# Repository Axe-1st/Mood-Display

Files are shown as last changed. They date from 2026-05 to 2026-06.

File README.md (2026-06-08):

# Mood-Display
## A Round Pin badge display! Powered by an Integrated ESP32-S3-WROOM-1 and a 1.28 in round display MoodBadge clips easily to your ID lanyard, keychain, belt, Bag, and so many more. You can easily express your mood or any animations you want to play on the display!

> Hiya! This project is still in its designing stage! When i build it, I will make a step by step video how to assemble 

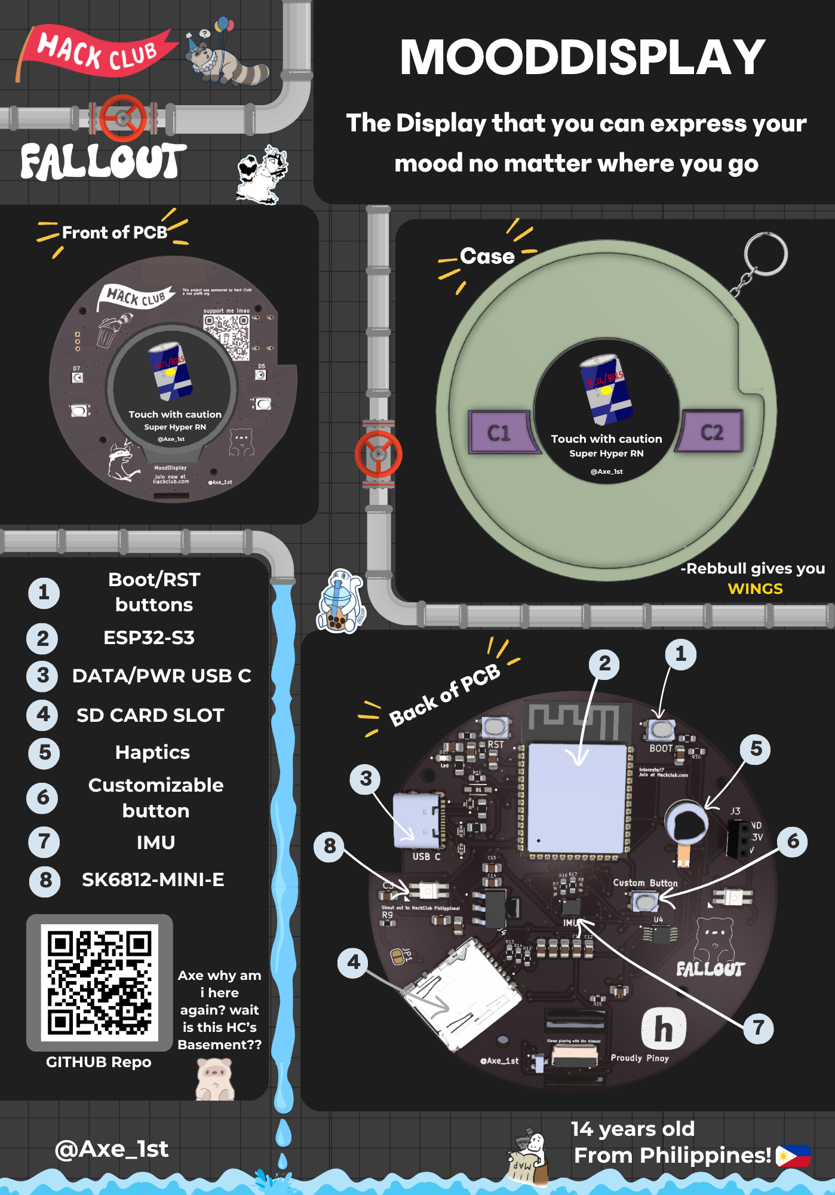
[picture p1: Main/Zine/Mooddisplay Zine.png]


> PDF is available in Zine folder!

### I made this project because i was inspired by those mini circular displays that you can bring anywhere! 
### This exsist since i wanted a badge that i can interact with.
### This project is pretty easy to do, All you need to do is follow the tutorial (Scoll down)

### Some kind of important notes!
- This is powered by USB C <b>ONLY</b>
- yes that means you have to always have a powerbank around with u to power it!
- reason for this: It would increase project cost and its complexity. 

## Schematic


> for a much better image check the pdf in extras!

## PCB


## PCB Render
- back


- Front


## Cad
- Onshape link:https://cad.onshape.com/documents/fe18899c0fc823d496ae247b/w/1ef647bd25a6a14e89f050fb/e/3a17c80e85047fb88fb13b3e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

> I love Onshape Man





## How to Build it 
- 1st step: Get the Requied materials in BOM.CSV and get the Gerber file in the folder production.
- 2nd Step: Pay JLC PCB to Fabricate the PCB and Use the links in the BOM.CSV to order parts
> You should def order a stencil! But for this tutorial i will be doing it manualy

- 3rd Step: Get your solder paste then manualy little solder to each pad that needs a connection. Also have a tissue nearby!
> Remember Patience is better than Crashing Out!

- 4th step: Start placing the compoments then when you are ready, use a hot plate to reflow all of the connections!
> For this part you would be Placing compoments at the back of the pcb so that means the front side of the pcb is facing flat on the hotplate
> When reflowing feel free to gently adjust the possiton of the compoments!

- 5th step: Now you have the backside of the pcb done! After letting the PCB rest now flip it to the other side, you should see some pads there. You are going to use a normal soldering iron to solder the buttons and other DIP compoments like the power Headers!

- 6th Step: Congradulations! You are done with the PCB!! Now kindly please test it by powering it on with a type C cable (please make sure it gets enough power to boot). Flash the test firmware i have provided it should light up the leds!

- if you like the bare PCB you can now stop here and use any of the mounting holes to attach the Mood-Display with anything!

- After this it would be Optional to do the case!

- 7th Step: Print all of the Case Parts then start assembling it by starting with the bottom. With the Bottom place the pcb on top and it line up with the mounting holes! When it is fully alligned screw the holes! Now get your assembles Bottom Case and carefully insert it up to the "middle case part" then super glue it! Now place and glue the Top Cover!
> i have used the terms "bottom case" "Middle Part" "Top Cover" why? because i have provided three parts in the CAD. 

- Final Step: There is no final step Lmao. Enjoy your own Mood display!

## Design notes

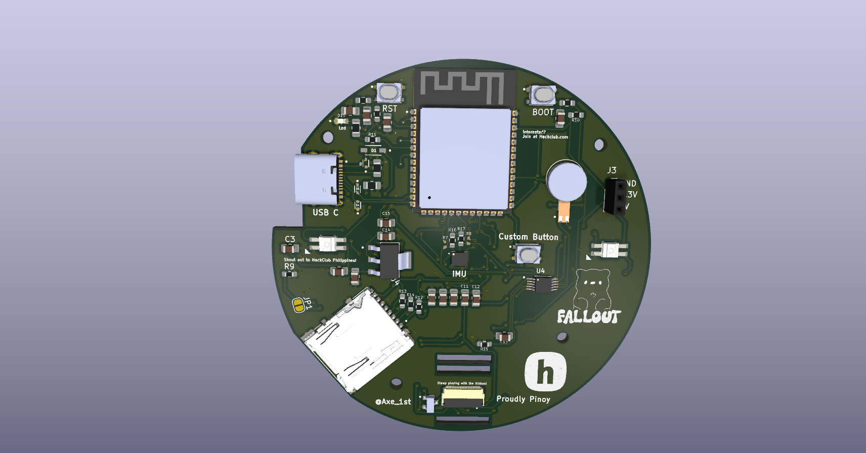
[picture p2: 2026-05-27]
Main/Extras/Display back.png

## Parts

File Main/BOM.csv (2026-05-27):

Product | Link | Quantity | Price USD | total
ESP32-S3-WROOM-1 | https://jlcpcb.com/partdetail/3198295-ESP32_S3_WROOM_1N4/C2913197 | 1 | $4.49 | $4.49
FFC2B28-12-G | https://www.digikey.ph/en/products/detail/gct/FFC2B28-12-G/10656933?s=N4IgTCBcDaIGJwMJgEJgBwFoCMZMHEACEAXQF8g | 1 | $0.40 | $0.40
LESD5D5.0CT1G | https://jlcpcb.com/partdetail/LRC-LESD5D50CT1G/C383211 | 3 | $0.40 | $1.20
1N5819HW-7-F | https://jlcpcb.com/partdetail/DiodesIncorporated-1N5819HW_7F/C82544 | 1 | $0.04 | $0.04
2.4k resistor | https://www.digikey.ph/en/products/detail/panasonic-industry/ERA-2AEB242X/1706014 | 2 | $0.11 | $0.22
4.7k resistor | https://www.digikey.ph/en/products/detail/yageo/RC0402JR-074K7L/726477 | 7 | $0.10 | $0.70
SK-Mini-e | https://jlcpcb.com/partdetail/OPSCOOptoelectronics-SK6812MINIE/C5149201 | 2 | $0.09 | $0.18
C2912598 | https://jlcpcb.com/partdetail/C2912598 | 2 | $0.08 | $0.16
Resistor | https://jlcpcb.com/partdetail/RESI-PTFR0805B200RP9/C2849095 | 5 | $0.07 | $0.35
Type C female | https://jlcpcb.com/parts/componentSearch?searchTxt=C2765186 | 1 | $0.09 | $0.09
JLCPCB | JLCPCB | 1 | $2.00 | $2.00
10uf cap | https://www.digikey.ph/en/products/detail/samsung-electro-mechanics/CL21A106KAYNNNG/3894413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 | 5 | $0.09 | $0.45
1uf capacitor | https://www.digikey.ph/en/products/detail/samsung-electro-mechanics/CL10A105KO8NNNC/3886692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 | 2 | $0.10 | $0.20
10 ohm resistor | https://www.digikey.ph/en/products/detail/stackpole-electronics-inc/RNCP0603FTD10K0/2240139 | 5 | $0.01 | $0.06
CAP CER 0.1UF 50V X7R 0603 | https://www.digikey.ph/en/products/detail/samsung-electro-mechanics/CL10B104KB8NNNL/3894274 | 10 | $0.03 | $0.27
4518-AMS1117-3.3TR-ND | https://www.digikey.ph/en/products/detail/umw/AMS1117-3-3/17635254 | 1 | $0.30 | $0.30
399-C0603C220J5GAC7867TR-ND | https://www.digikey.ph/en/products/detail/kemet/C0603C220J5GACTU/411055 | 2 | $0.13 | $0.26
smd Buttons | https://www.digikey.ph/en/products/detail/c-k/PTS810SJG250SMTR-LFS/4176612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 | 5 | $0.65 | $3.25
Pwr led | https://www.digikey.ph/en/products/detail/liteon/LTST-C190TBKT/388529?s=N4IgTCBcDaIIwDYAMBaRAWBKwoHIBEQBdAXyA | 1 | $0.17 | $0.17
2N7002 | https://www.digikey.ph/en/products/detail/diotec-semiconductor/2N7002/13163336 | 1 | $0.16 | $0.16
DLC-T1.3CDS#1 | https://www.digikey.ph/en/products/detail/dlc-display-co-ltd/DLC-T1-3CDS-1/26822644 | 1 | $17.97 | $17.97
C0720B001F | https://www.digikey.ph/en/products/detail/vybronics-inc/VC0720B001F/6009905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 | 1 | $3.23 | $3.23
DRV2605LDGST | https://www.digikey.ph/en/products/detail/texas-instruments/DRV2605LDGST/5023854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 | 1 | $3.45 | $3.45
BMI270 | https://www.digikey.ph/en/products/detail/bosch-sensortec/BMI270/9974486 | 1 | $4.23 | $4.23
DM3AT-SF-PEJM5 | https://www.digikey.com/en/products/detail/hirose-electric-co-ltd/DM3AT-SF-PEJM5/2533565 | 1 | $2.85 | $2.85
 |  |  |  | TOTAL
 |  |  |  | $36.15

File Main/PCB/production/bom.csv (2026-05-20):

Designator | Footprint | Quantity | Value | LCSC Part #
C1, C14, C2, C4, C7 | 0805 | 5 | 10uF
C10, C15, C3, C5, C6, C9 | 0805 | 6 | 0u1F
C11, C12 | 0805 | 2 | 100nF
C13, C8 | 0805 | 2 | 1uF
D1 | SOD3715X145N | 1 | 1N5819HW-7-F
D15 | LEDC1608X35N | 1 | LTST-C190KGKT
D2, D3, D4 | TVS_LESD5D5.0CT1G | 3 | LESD5D5.0CT1G
D5, D7 | SK6812MINI-E_fixed | 2 | SK6812MINI-E
J1 | HRO_TYPE-C-31-M-12 | 1 | TYPE-C-31-M-12
J2 | GCT_FFC2B28-12-G | 1 | FFC2B28-12-G
J3 | PinSocket_1x03_P2.00mm_Vertical | 1 | Conn_01x03
J4 | HRS_DM3AT-SF-PEJM5 | 1 | DM3AT-SF-PEJM5
M1 | XDCR_C0720B001F | 1 | C0720B001F
Q1 | TRANS_2N7002 | 1 | 2N7002
R1, R2 | 0805 | 2 | 5k1
R10, R11, R12, R13, R14, R16, R17 | 0603 | 7 | 4.7k
R15, R4, R5, R6, R9 | 0603 | 5 | 10k
R3 | 0805 | 1 | 75
R7, R8 | RES_ERA2AEB242X | 2 | 2.4k
SW1, SW2, SW3, SW4, SW5 | SW_PTS810_SJM_250_SMTR_LFS | 5 | PTS810_SJM_250_SMTR_LFS
U1 | SOT229P700X180-4N | 1 | AMS1117-3.3
U2 | XCVR_ESP32-S3-WROOM-1-N16R2 | 1 | ESP32-S3-WROOM-1-N16R2
U3 | XDCR_BMI270 | 1 | BMI270
U4 | SOP50P490X110-10N | 1 | DRV2605LDGST

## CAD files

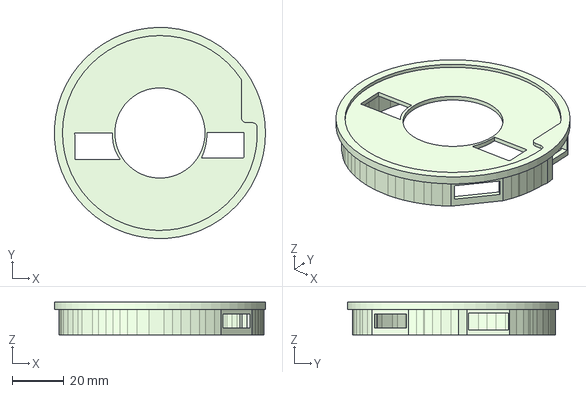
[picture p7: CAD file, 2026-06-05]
Main/CAD/Part Studio 1 - Top Case cover.step
81.6 x 81.6 x 12.7 mm

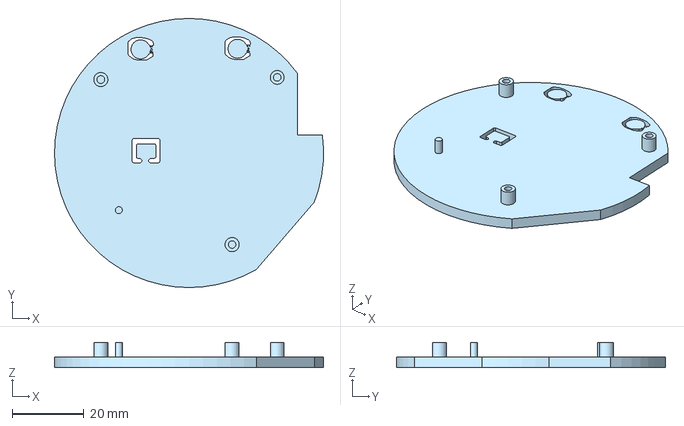
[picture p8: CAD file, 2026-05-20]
Production/CAD/Part Studio 1 - Bottom Case.step
75.0 x 75.1 x 7.00 mm

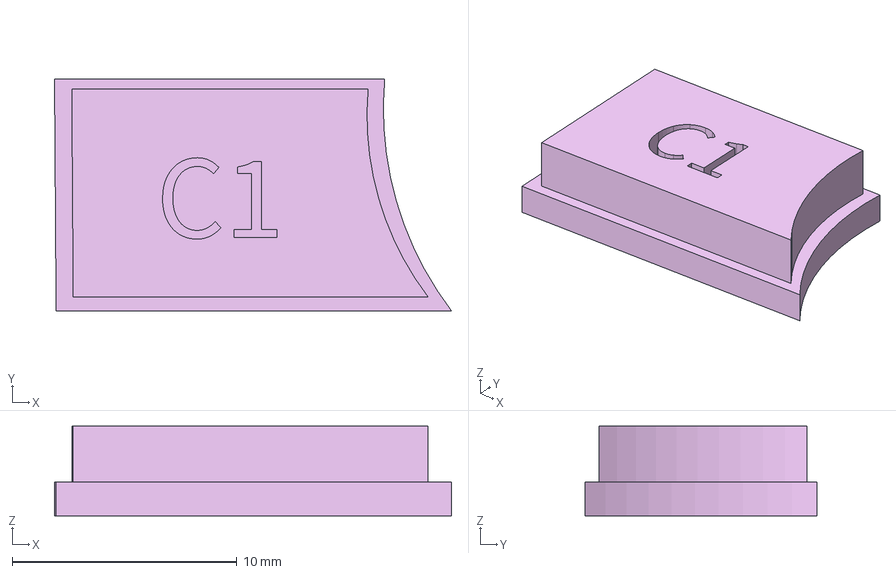
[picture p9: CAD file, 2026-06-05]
Main/CAD/Part Studio 1 - Left Button.step
17.7 x 10.3 x 4.00 mm

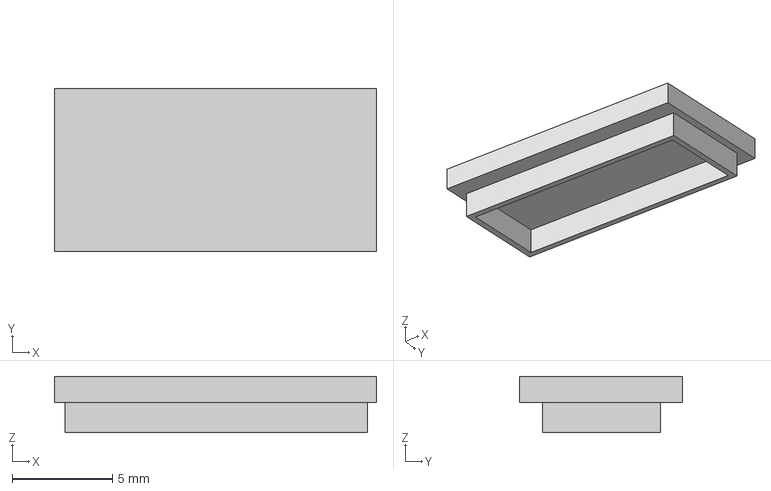
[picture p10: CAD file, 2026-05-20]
Production/CAD/Part Studio 1 - USB C COVER.step
16.1 x 8.13 x 2.80 mm

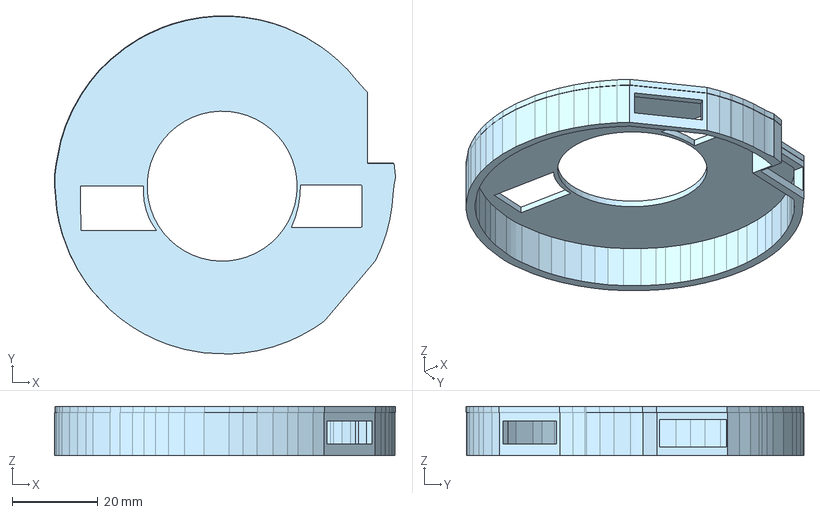
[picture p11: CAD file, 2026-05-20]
Production/CAD/Part Studio 1 - Top Case cover.step
79.4 x 78.6 x 11.5 mm

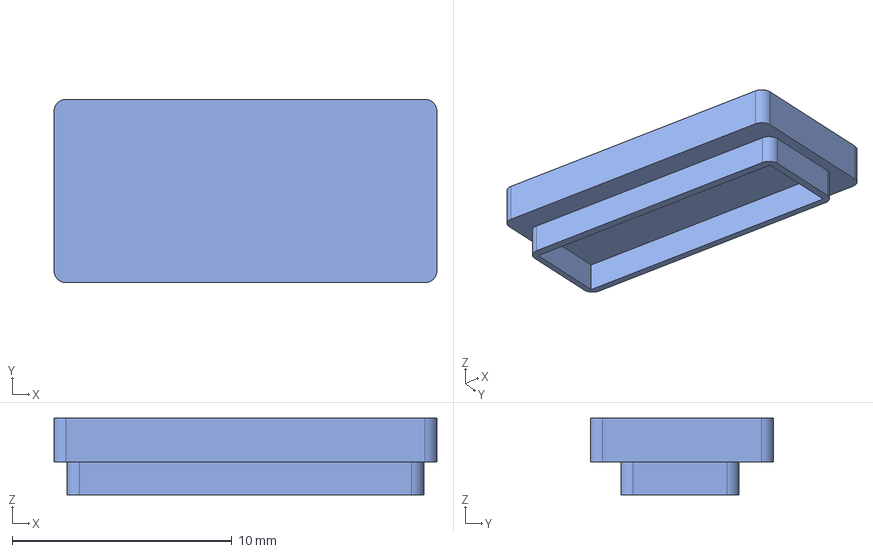
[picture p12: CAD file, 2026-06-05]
Main/CAD/Part Studio 1 - SD Card slot Cover.step
17.4 x 8.35 x 3.50 mm

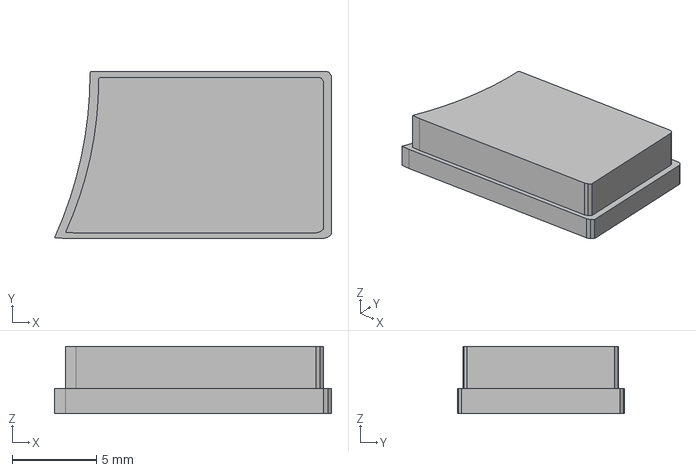
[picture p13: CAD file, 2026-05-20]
Production/CAD/Part Studio 1 - Right Button.step
16.4 x 9.92 x 4.00 mm

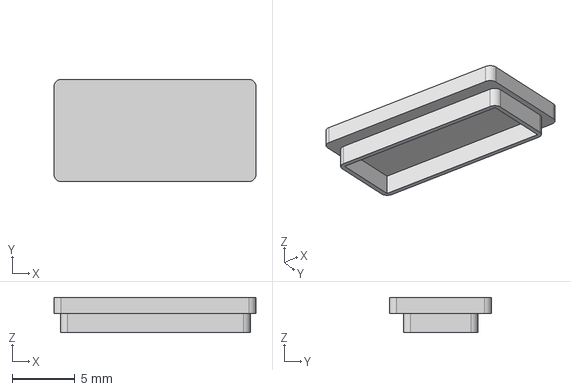
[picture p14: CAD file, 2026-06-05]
Main/CAD/Part Studio 1 - USB C COVER.step
16.1 x 8.13 x 2.80 mm

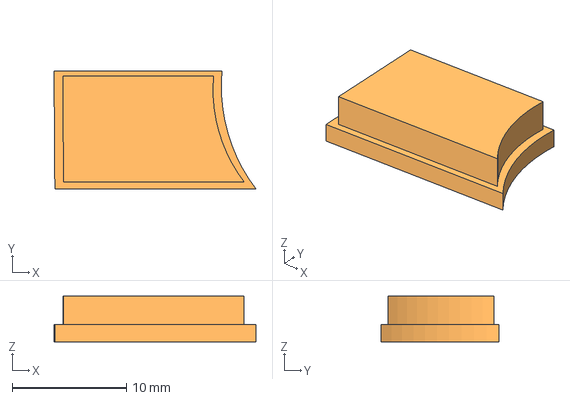
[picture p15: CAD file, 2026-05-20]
Production/CAD/Part Studio 1 - Left Button.step
17.7 x 10.3 x 4.00 mm

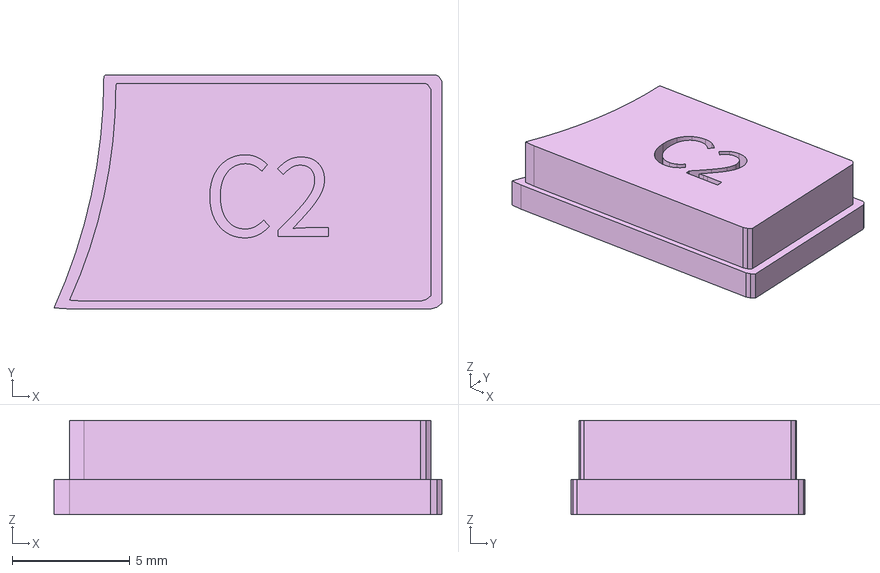
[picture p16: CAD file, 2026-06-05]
Main/CAD/Part Studio 1 - Right Button.step
16.4 x 9.92 x 4.00 mm

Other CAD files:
Main/CAD/Part Studio 1 - Bottom Case.step
Production/CAD/Part Studio 1 - SD Card slot Cover.step

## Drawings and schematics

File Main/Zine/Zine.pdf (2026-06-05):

# MOODDISPLAY

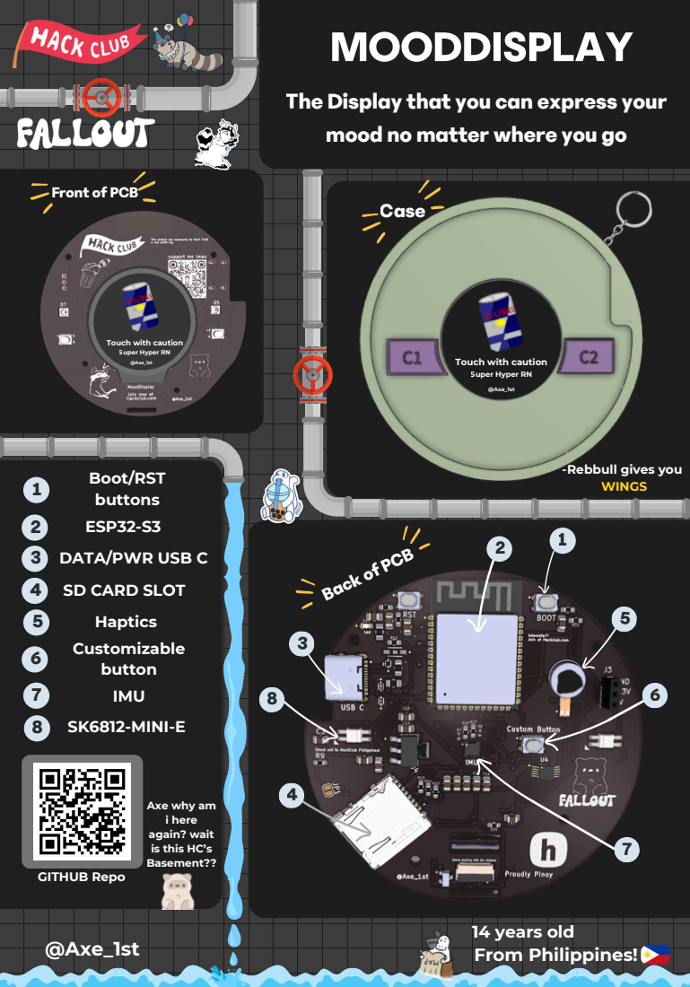
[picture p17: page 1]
From Philippines!; Case; @Axe_1st; Boot/RST buttons; ESP32-S3; DATA/PWR USB C; SD CARD SLOT; Haptics; Customizable button; IMU; SK6812-MINI-E; 14 years old; GITHUB Repo

The Display that you can express your
mood no matter where you go

Front of PCB

Touch with caution
Super Hyper RN @Axe_1st

-Rebbull gives you
WINGS

Back of PCB

Axe why am
i here
again? wait
is this HC’s
Basement??

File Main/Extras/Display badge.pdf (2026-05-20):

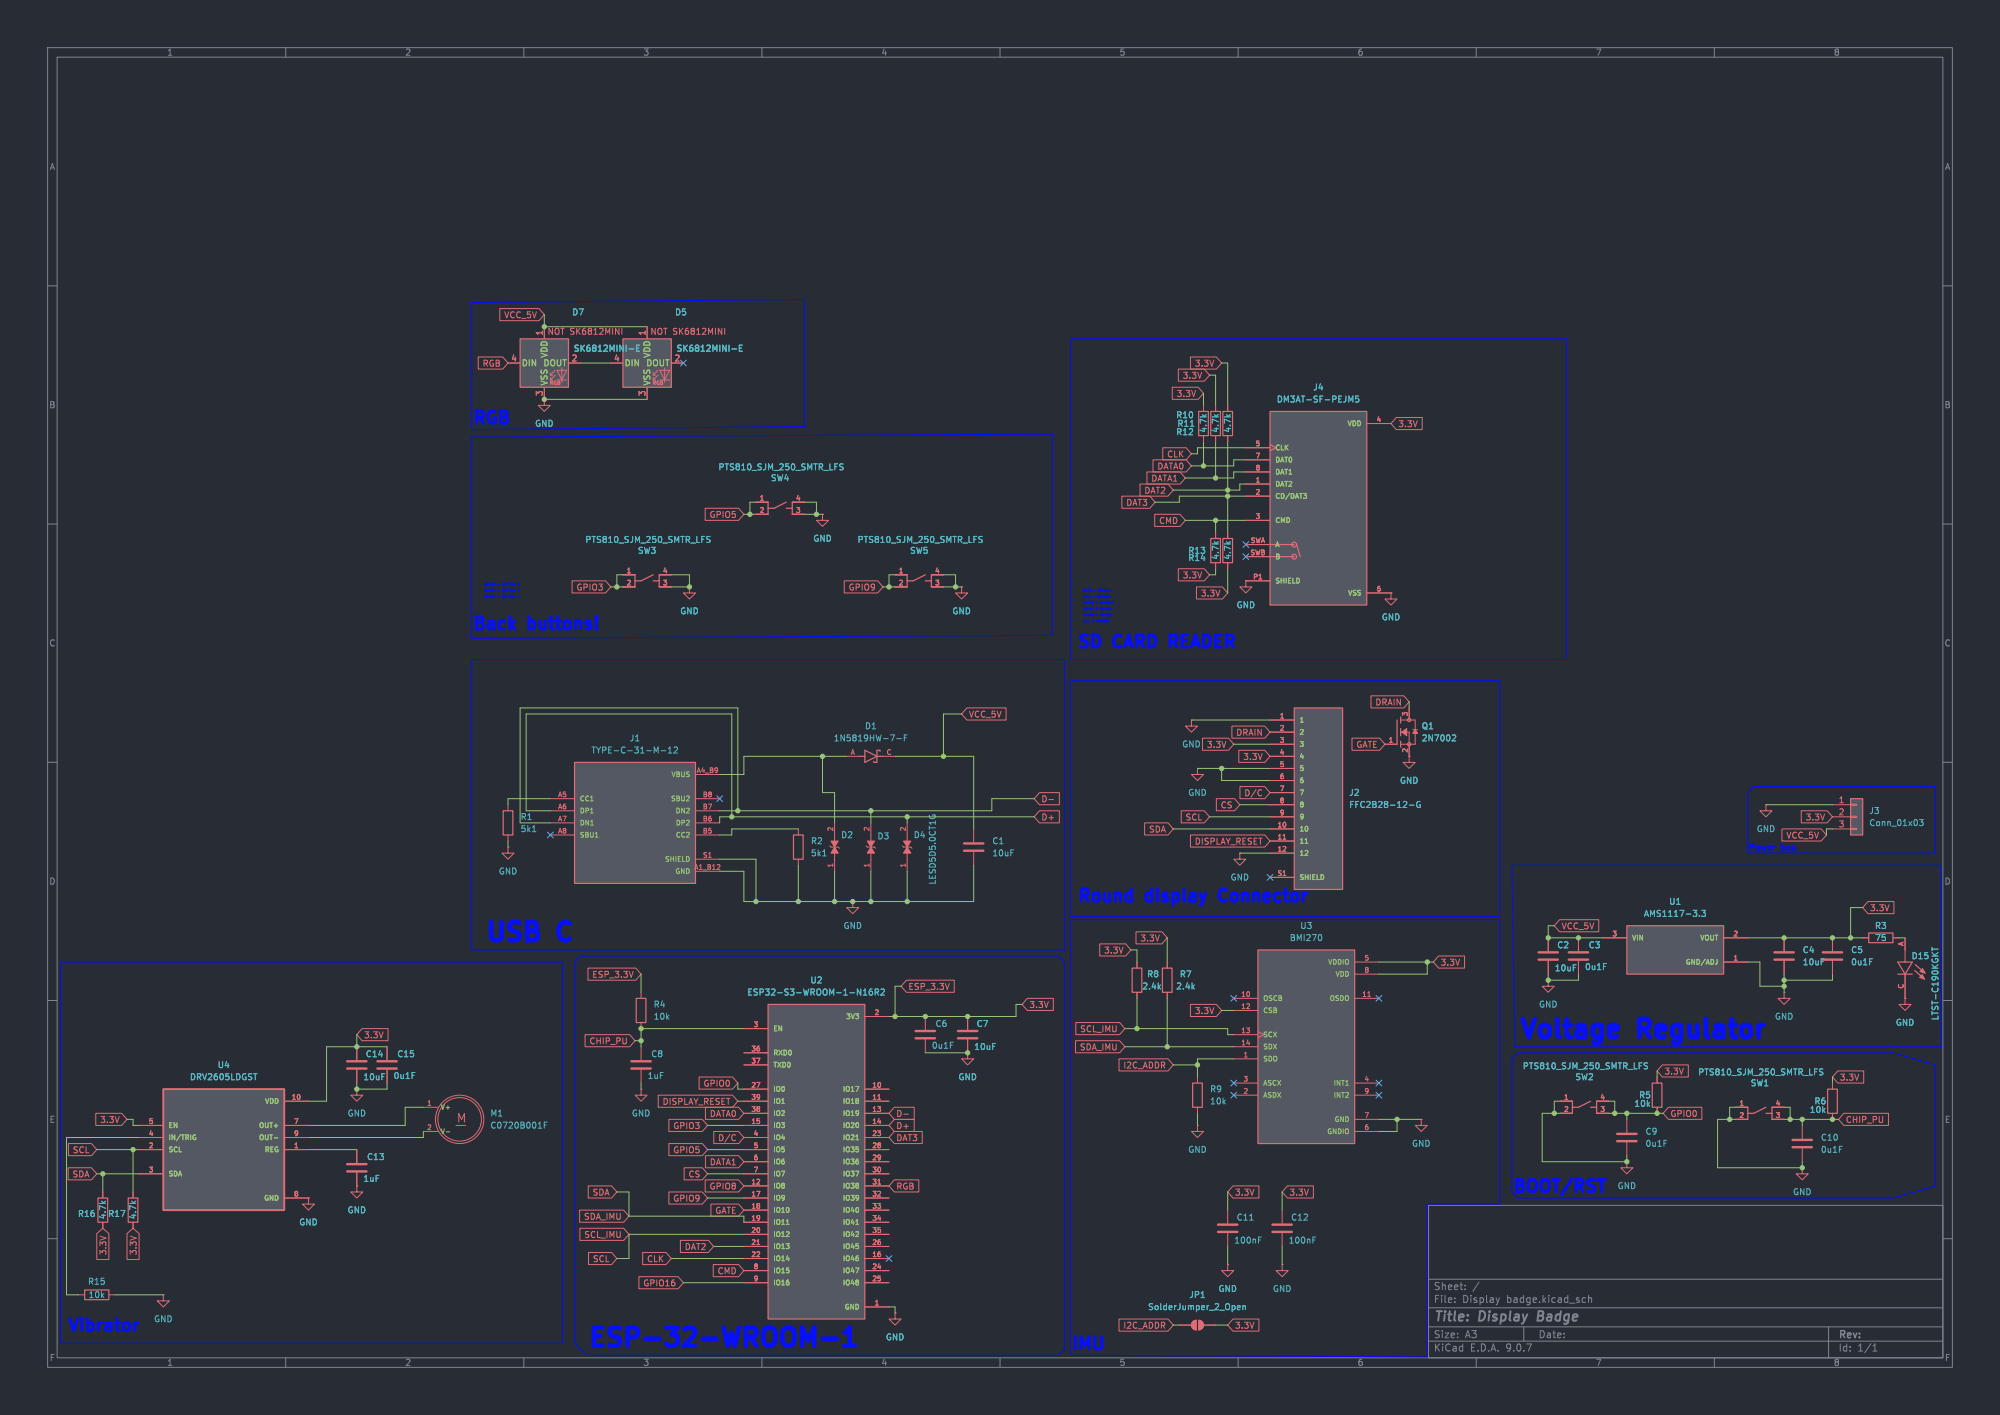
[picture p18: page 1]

GPIO9 = BUTTON 3 GPIO3 = BUTTON 1 GPIO5 = BUTTON 2 Back buttons!

DATA1 = GPIO6 CLK = GPIO14 DATA2 = GPIO13 Round display Connector
DATA0 = GPIO2 SD CARD READER

Id: 1/1 Title: Display Badge

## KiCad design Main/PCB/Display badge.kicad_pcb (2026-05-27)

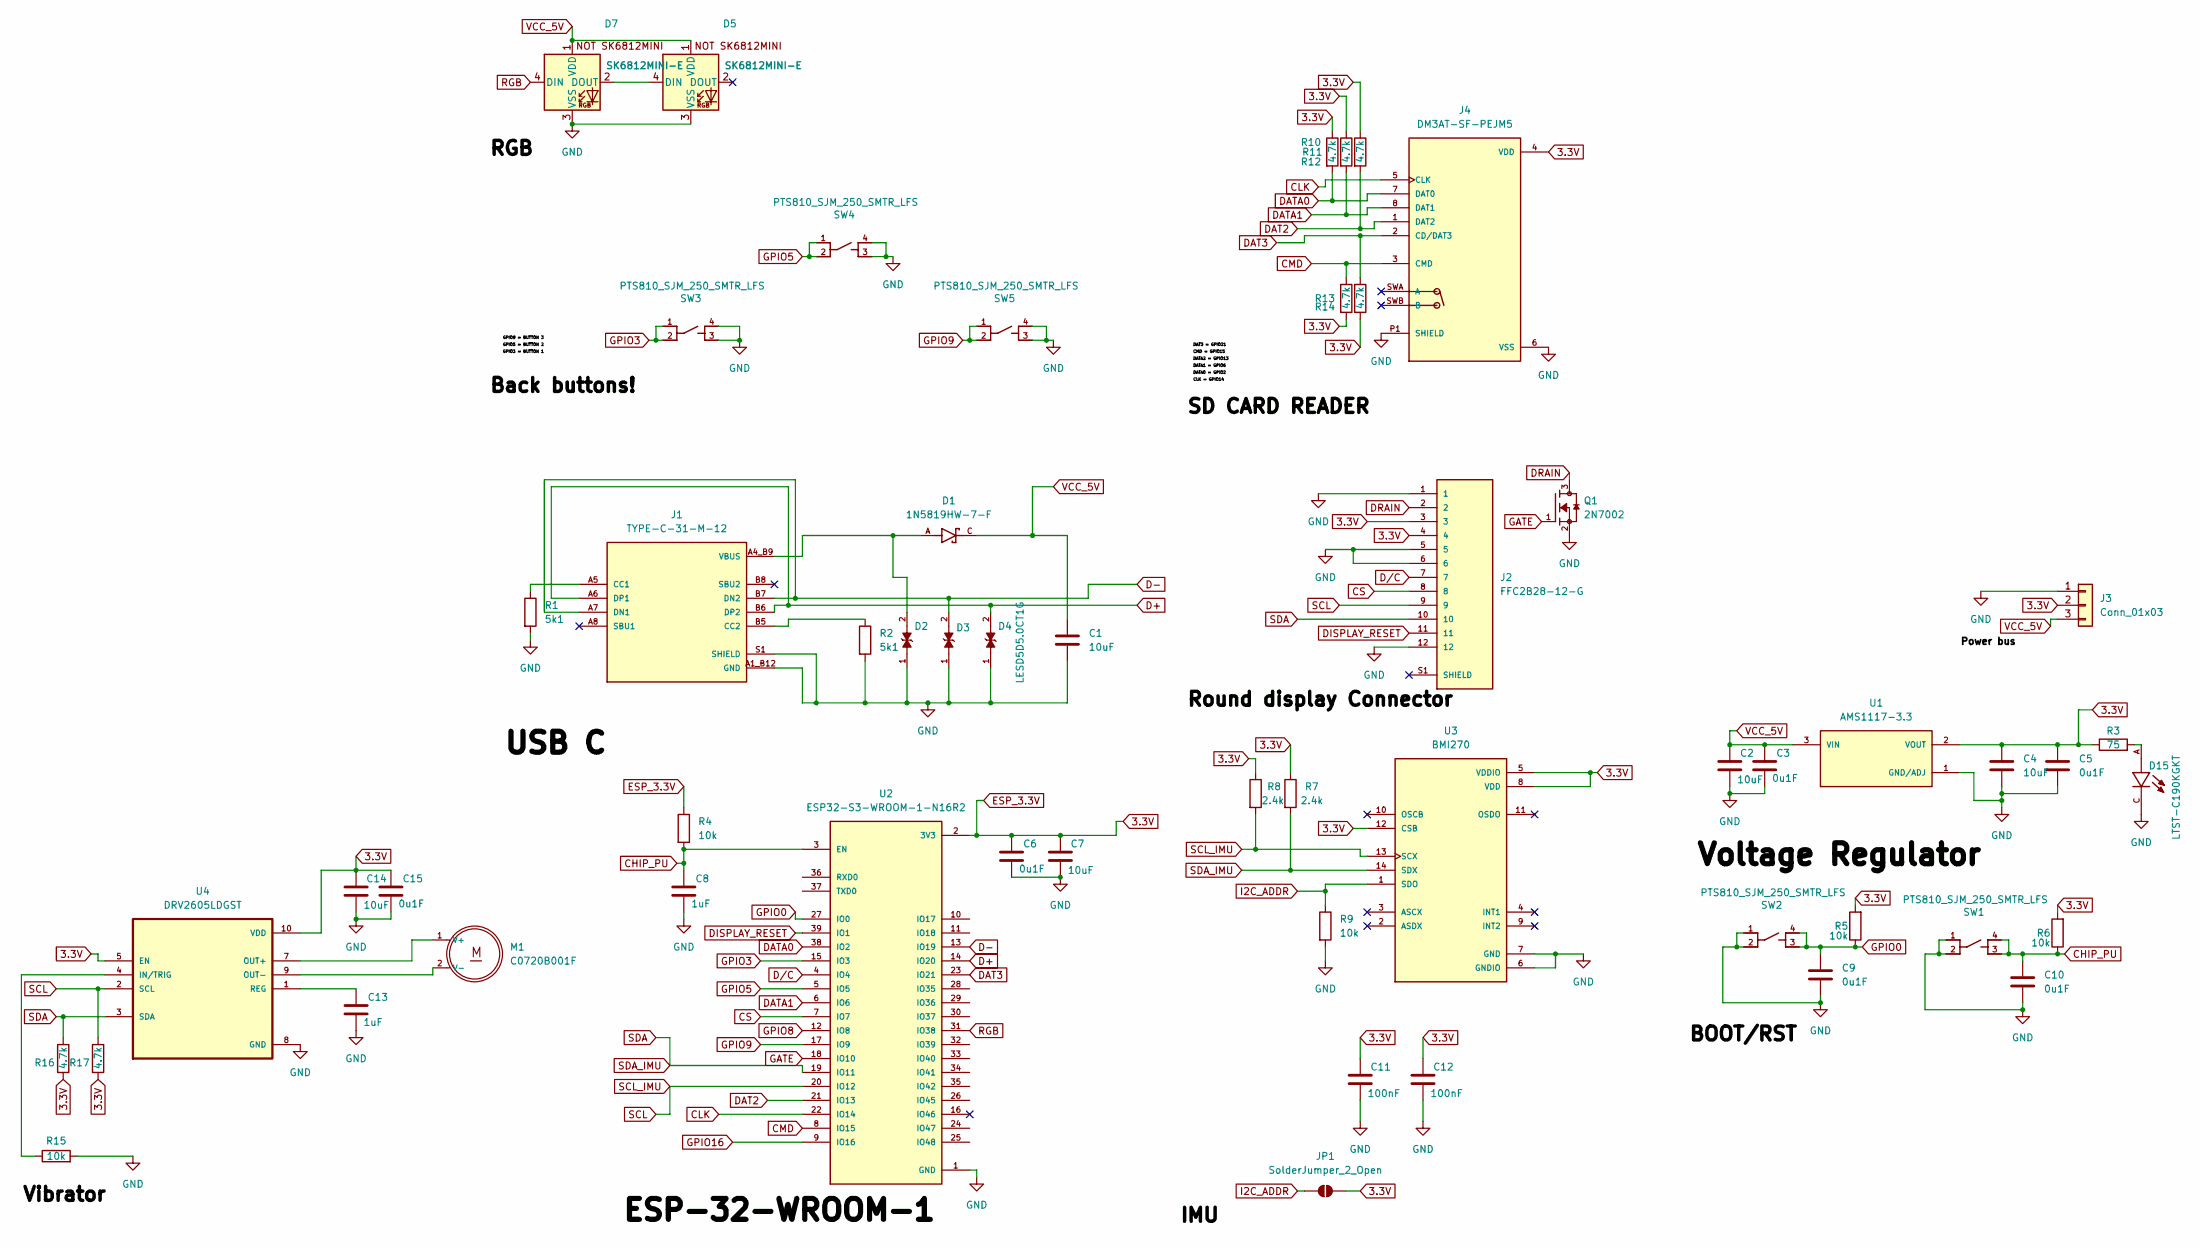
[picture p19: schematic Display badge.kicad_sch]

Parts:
C1, C2, C4, C7, C14: 10uF; C_0805_2012Metric_Pad1.18x1.45mm_HandSolder
C3, C5, C6, C9, C10, C15: 0u1F; C_0805_2012Metric_Pad1.18x1.45mm_HandSolder
C8, C13: 1uF; C_0805_2012Metric_Pad1.18x1.45mm_HandSolder
C11, C12: 100nF; C_0805_2012Metric_Pad1.18x1.45mm_HandSolder
D1: 1N5819HW-7-F; SOD3715X145N; PARTREV 18-2
D2, D3, D4: LESD5D5.0CT1G; TVS_LESD5D5.0CT1G; PARTREV O
D5, D7: SK6812MINI-E; SK6812MINI-E_fixed
D15: LTST-C190KGKT; LEDC1608X35N
J1: TYPE-C-31-M-12; HRO_TYPE-C-31-M-12; PARTREV 2020.12.08
J2: FFC2B28-12-G; GCT_FFC2B28-12-G; PARTREV A
J3: Conn_01x03; PinSocket_1x03_P2.00mm_Vertical
J4: DM3AT-SF-PEJM5; HRS_DM3AT-SF-PEJM5; PARTREV 20200913
JP1: SolderJumper_2_Open; SolderJumper-2_P1.3mm_Open_RoundedPad1.0x1.5mm
M1: C0720B001F; XDCR_C0720B001F
Q1: 2N7002; TRANS_2N7002; PARTREV 2023-01-11
R1, R2: 5k1; R_0805_2012Metric_Pad1.20x1.40mm_HandSolder
R3: 75; R_0805_2012Metric_Pad1.20x1.40mm_HandSolder
R4, R5, R6, R9, R15: 10k; R_0603_1608Metric_Pad0.98x0.95mm_HandSolder
R7, R8: 2.4k; RES_ERA2AEB242X
R10, R11, R12, R13, R14, R16, R17: 4.7k; R_0603_1608Metric_Pad0.98x0.95mm_HandSolder
SW1, SW2, SW3, SW4, SW5: PTS810_SJM_250_SMTR_LFS; SW_PTS810_SJM_250_SMTR_LFS
U1: AMS1117-3.3; SOT229P700X180-4N; PARTREV N/A
U2: ESP32-S3-WROOM-1-N16R2; XCVR_ESP32-S3-WROOM-1-N16R2; PARTREV v1.0
U3: BMI270; XDCR_BMI270
U4: DRV2605LDGST; SOP50P490X110-10N

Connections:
3.3V: C4.1, C5.1, C6.1, C7.1, C11.1, C12.1, C14.1, C15.1, J2.3, J2.4, J3.2, J4.4 (VDD), JP1.2 (B), R3.1, R4.1, R5.2, R6.2, R7.1, R8.1, R10.1, R11.1, R12.1, R13.2, R14.2, R16.2, R17.2, U1.2 (VOUT), U2.2 (3V3), U3.5 (VDDIO), U3.8 (VDD), U3.12 (CSB), U4.5 (EN), U4.10 (VDD)
CHIP_PU: C8.1, C10.1, R4.2, R6.1, SW1.3, SW1.4, U2.3 (EN)
CLK: J4.5 (CLK), U2.22 (IO14)
CMD: J4.3 (CMD), R13.1, U2.8 (IO15)
CS: J2.8, U2.7 (IO7)
D+: D4.2, J1.A6 (DP1), J1.B6 (DP2), U2.14 (IO20)
D-: D3.2, J1.A7 (DN1), J1.B7 (DN2), U2.13 (IO19)
DAT2: J4.1 (DAT2), R12.2, U2.21 (IO13)
DAT3: J4.2 (CD/DAT3), R14.1, U2.23 (IO21)
DATA0: J4.7 (DAT0), R10.2, U2.38 (IO2)
DATA1: J4.8 (DAT1), R11.2, U2.6 (IO6)
DISPLAY_RESET: J2.11, U2.39 (IO1)
DRAIN: J2.2, Q1.3
D/C: J2.7, U2.4 (IO4)
GATE: Q1.1, U2.18 (IO10)
GND: C1.2, C2.2, C3.2, C4.2, C5.2, C6.2, C7.2, C8.2, C9.2, C10.2, C11.2, C12.2, C13.2, C14.2, C15.2, D2.1, D3.1, D4.1, D5.3 (VSS), D7.3 (VSS), D15.C, J1.A1_B12 (GND), J1.B1_A12 (GND), J1.S1 (SHIELD), J1.S2 (SHIELD), J1.S3 (SHIELD), J1.S4 (SHIELD), J2.1, J2.5, J2.6, J2.12, J3.1, J4.6 (VSS), J4.P1 (SHIELD), J4.P2 (SHIELD), J4.P3 (SHIELD), J4.P4 (SHIELD), Q1.2, R1.2, R2.2, R9.2, R15.2, SW1.1, SW1.2, SW2.1, SW2.2, SW3.3, SW3.4, SW4.3, SW4.4, SW5.3, SW5.4, U1.1 (GND/ADJ), U2.1 (GND), U2.40 (GND), U2.41_1 (GND), U2.41_2 (GND), U2.41_3 (GND), U2.41_4 (GND), U2.41_5 (GND), U2.41_6 (GND), U2.41_7 (GND), U2.41_8 (GND), U2.41_9 (GND), U3.6 (GNDIO), U3.7 (GND), U4.8 (GND)
GPIO0: C9.1, R5.1, SW2.3, SW2.4, U2.27 (IO0)
GPIO3: SW3.1, SW3.2, U2.15 (IO3)
GPIO5: SW4.1, SW4.2, U2.5 (IO5)
GPIO8: U2.12 (IO8)
GPIO9: SW5.1, SW5.2, U2.17 (IO9)
GPIO16: U2.9 (IO16)
I2C_ADDR: JP1.1 (A), R9.1, U3.1 (SDO)
unnamed: D5.4 (DIN), D7.2 (DOUT)
unnamed: D15.A, R3.2
unnamed: J1.A5 (CC1), R1.1
unnamed: J1.B5 (CC2), R2.1
unnamed: M1.1 (V+), U4.7 (OUT+)
unnamed: M1.2 (V-), U4.9 (OUT-)
unnamed: R15.1, U4.4 (IN/TRIG)
unnamed: C13.1, U4.1 (REG)
RGB: D7.4 (DIN), U2.31 (IO38)
SCL: J2.9, R8.2, R17.1, U2.20 (IO12), U3.13 (SCX), U4.2 (SCL)
SDA: J2.10, R7.2, R16.1, U2.19 (IO11), U3.14 (SDX), U4.3 (SDA)
VBUS: D1.A, D2.2, J1.A4_B9 (VBUS), J1.B4_A9 (VBUS)
VCC_5V: C1.1, C2.1, C3.1, D1.C, D5.1 (VDD), D7.1 (VDD), J3.3, U1.3 (VIN)

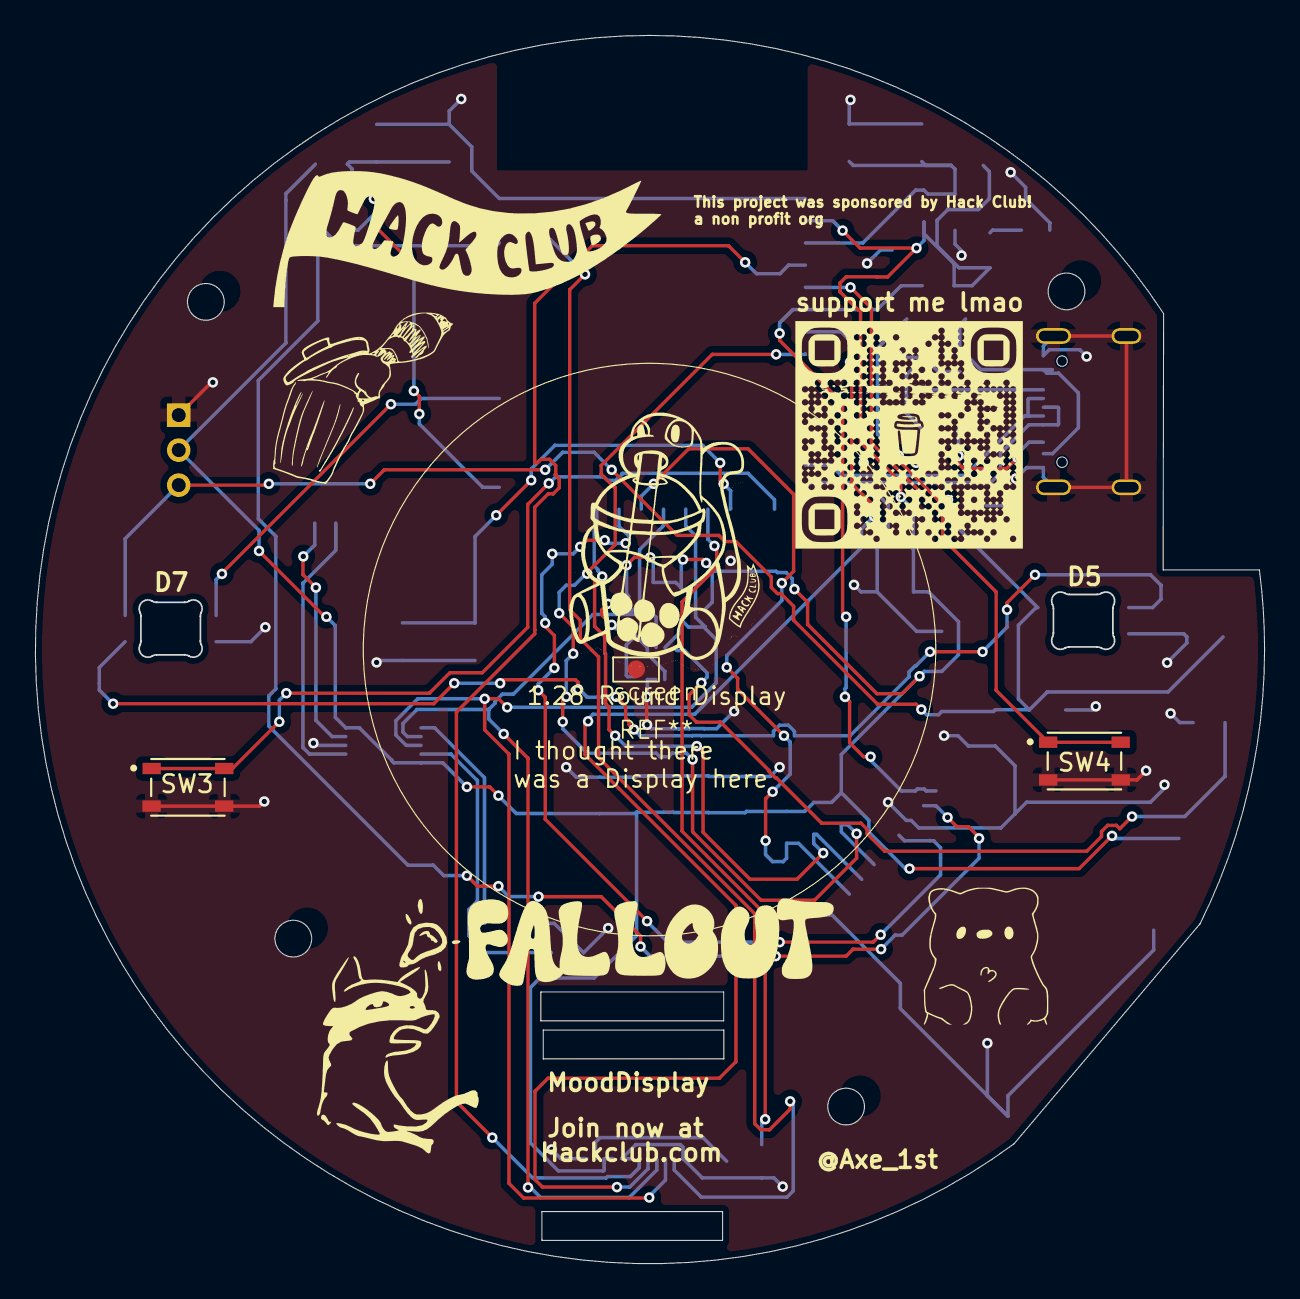
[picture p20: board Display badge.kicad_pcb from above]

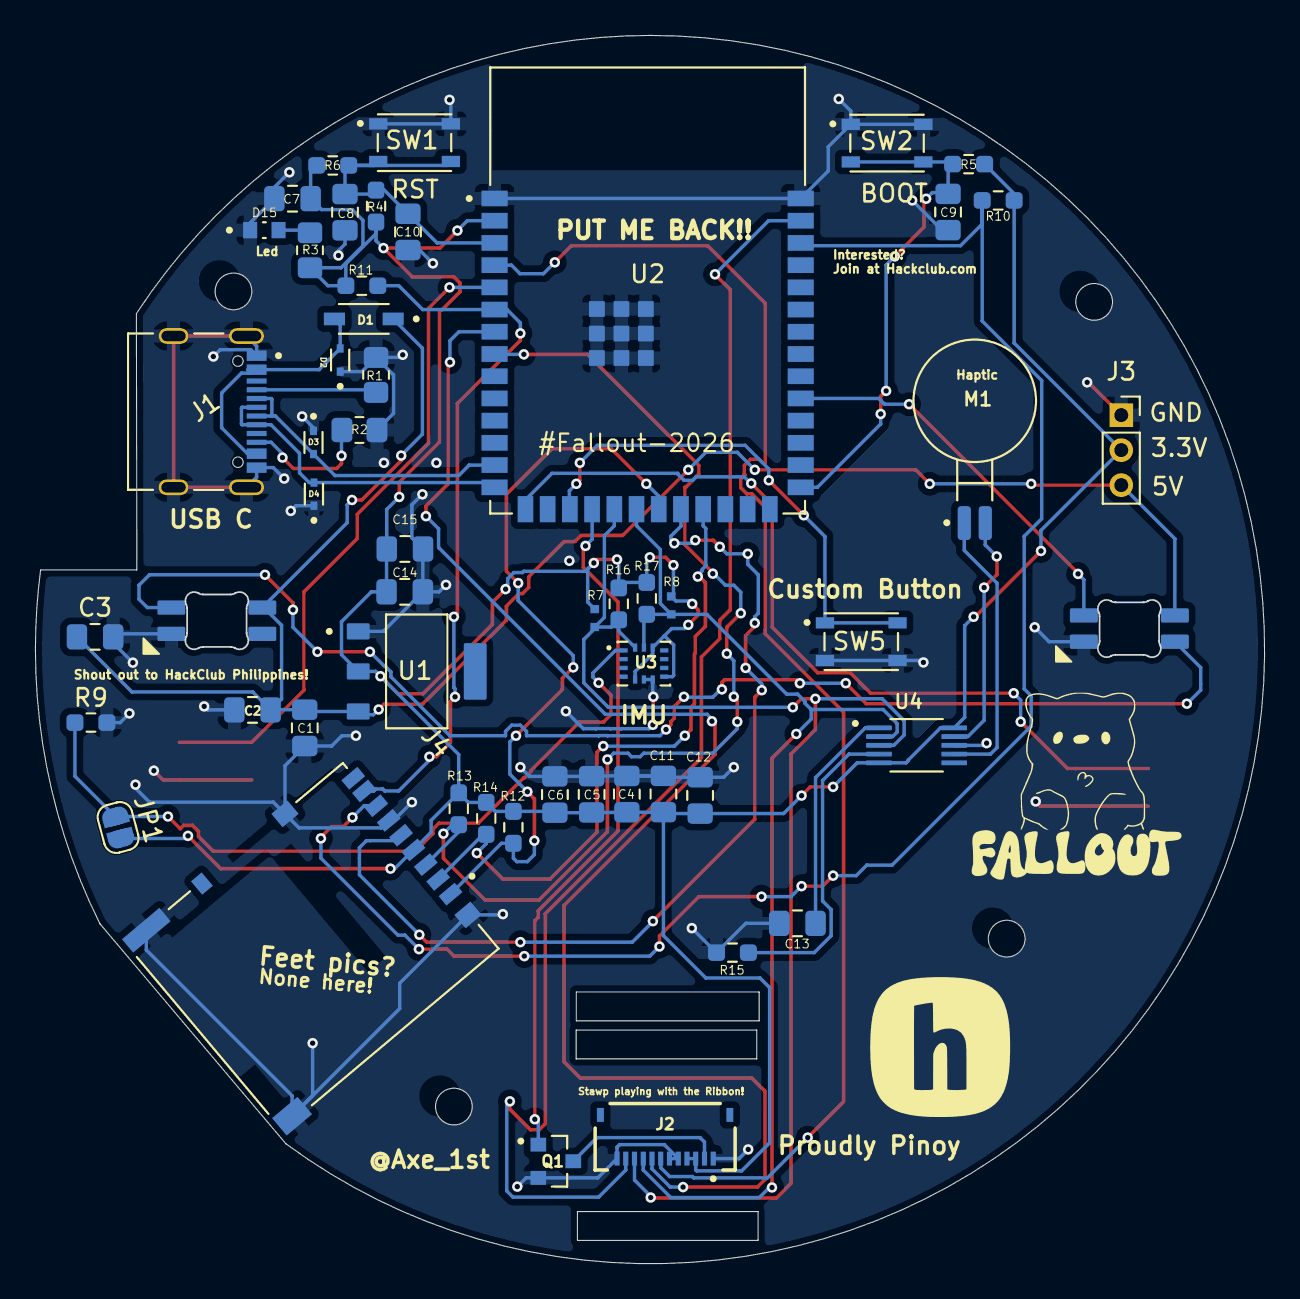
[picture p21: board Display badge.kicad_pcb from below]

Board: 2 copper layers, 70.3 x 70.2 mm, 55 parts (51 on the bottom side), 34 nets.

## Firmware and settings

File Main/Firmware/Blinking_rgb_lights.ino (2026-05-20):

#include <Adafruit_NeoPixel.h>
#define LED_PIN  4 
#define NUM_LEDS 2
Adafruit_NeoPixel strip(NUM_LEDS, LED_PIN, NEO_GRB + NEO_KHZ800);

void setup() {
strip.begin();
strip.show();
}

void loop() {  ///flash leds
strip.fill(strip.Color(255, 255, 255));
strip.show();
delay(350);
strip.clear();
strip.show();
delay(350);
}

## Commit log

2026-05-20 Added Basic Repo requirements
    [Display badge.kicad_pcb, Display badge.kicad_sch, bom.csv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]
2026-05-20 Added CAD to Main
    [Part Studio 1 - Bottom Case.step, Part Studio 1 - Left Button.step, Part Studio 1 - Right Button.step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]
2026-05-27 ZINE IS OUT
    [Display badge.kicad_pcb]
2026-05-27 Added BOM
    [BOM.csv]
2026-05-27 Zine Update
    [BOM.csv, Display badge.kicad_pcb]
2026-06-04 Fixed Buttons
    Fixed the buttons because the buttons are black which caused it to look like there is no buttons!
2026-06-05 Impov Case!
    [Part Studio 1 - Bottom Case.step, Part Studio 1 - Left Button.step, Part Studio 1 - Right Button.step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]
